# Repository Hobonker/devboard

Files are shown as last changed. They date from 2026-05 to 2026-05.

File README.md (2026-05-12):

# Devboard

# Inspiration 
I've never done such a large and complex custom PCB before, so I wanted to learn how to. The project helped me learn a lot about wiring and challenged me.
# What is it?
It's a custom PCB using an rp2040. Some other features are flash memory, USB-C power input, 12MHz crystal oscillator and a MCP1700 LDO voltage regulator.

# PCB
Here are some images of the board
Screenshot 2026-05-03 at 10.16.09 PM
Screenshot 2026-05-07 at 10 12 39 PM
Screenshot 2026-05-07 at 10 13 23 PM

# Bom
| Top Designator | Total Price ($) | Product Link |
|---|---|---|
| C1, C10 | 0.029 | https://jlcpcb.com/partdetail/53938-CL05A105KA5NQNC/C52923 |
| C8, C6, C5, C4, C2, C7, C11, C9, C12, C17, C3 | 0.0605 | https://jlcpcb.com/partdetail/1877-CL05B104KO5NNNC/C1525 |
| C13, C14 | 0.056 | https://jlcpcb.com/partdetail/20411-CL10A106KP8NNNC/C19702 |
| C16, C15 | 0.01 | https://jlcpcb.com/partdetail/1914-0402CG330J500NT/C1562 |
| J1 | 0.18 | https://jlcpcb.com/partdetail/Korean_HropartsElec-TYPE_C_31_M12/C165948 |
| J3, J2 | 0.14 | https://jlcpcb.com/partdetail/51993-2_54_1_20P/C50981 |
| J4 | 0.03 | https://jlcpcb.com/partdetail/25717-1_27_1_3P/C24980 |
| R2, R1 | 0.005 | https://jlcpcb.com/partdetail/26648-0402WGF5101TCE/C25905 |
| R3, R4 | 0.011 | https://jlcpcb.com/partdetail/25843-0402WGF270JTCE/C25100 |
| R6, R5 | 0.005 | https://jlcpcb.com/partdetail/12256-0402WGF1001TCE/C11702 |
| R7 | 0.0025 | https://jlcpcb.com/partdetail/26487-0402WGF1002TCE/C25744 |
| SW1 | 0.06 | https://jlcpcb.com/partdetail/XUNPU-TS_1088AR02016/C720477 |
| U1 | 0.98 | https://jlcpcb.com/partdetail/RaspberryPi-RP2040/C2040 |
| U2 | 0.49 | https://jlcpcb.com/partdetail/MicrochipTech-MCP1700T_3302ETT/C39051 |
| U4 | 0.71 | https://jlcpcb.com/partdetail/WinbondElec-W25Q16JVUXIQ/C2843335 |

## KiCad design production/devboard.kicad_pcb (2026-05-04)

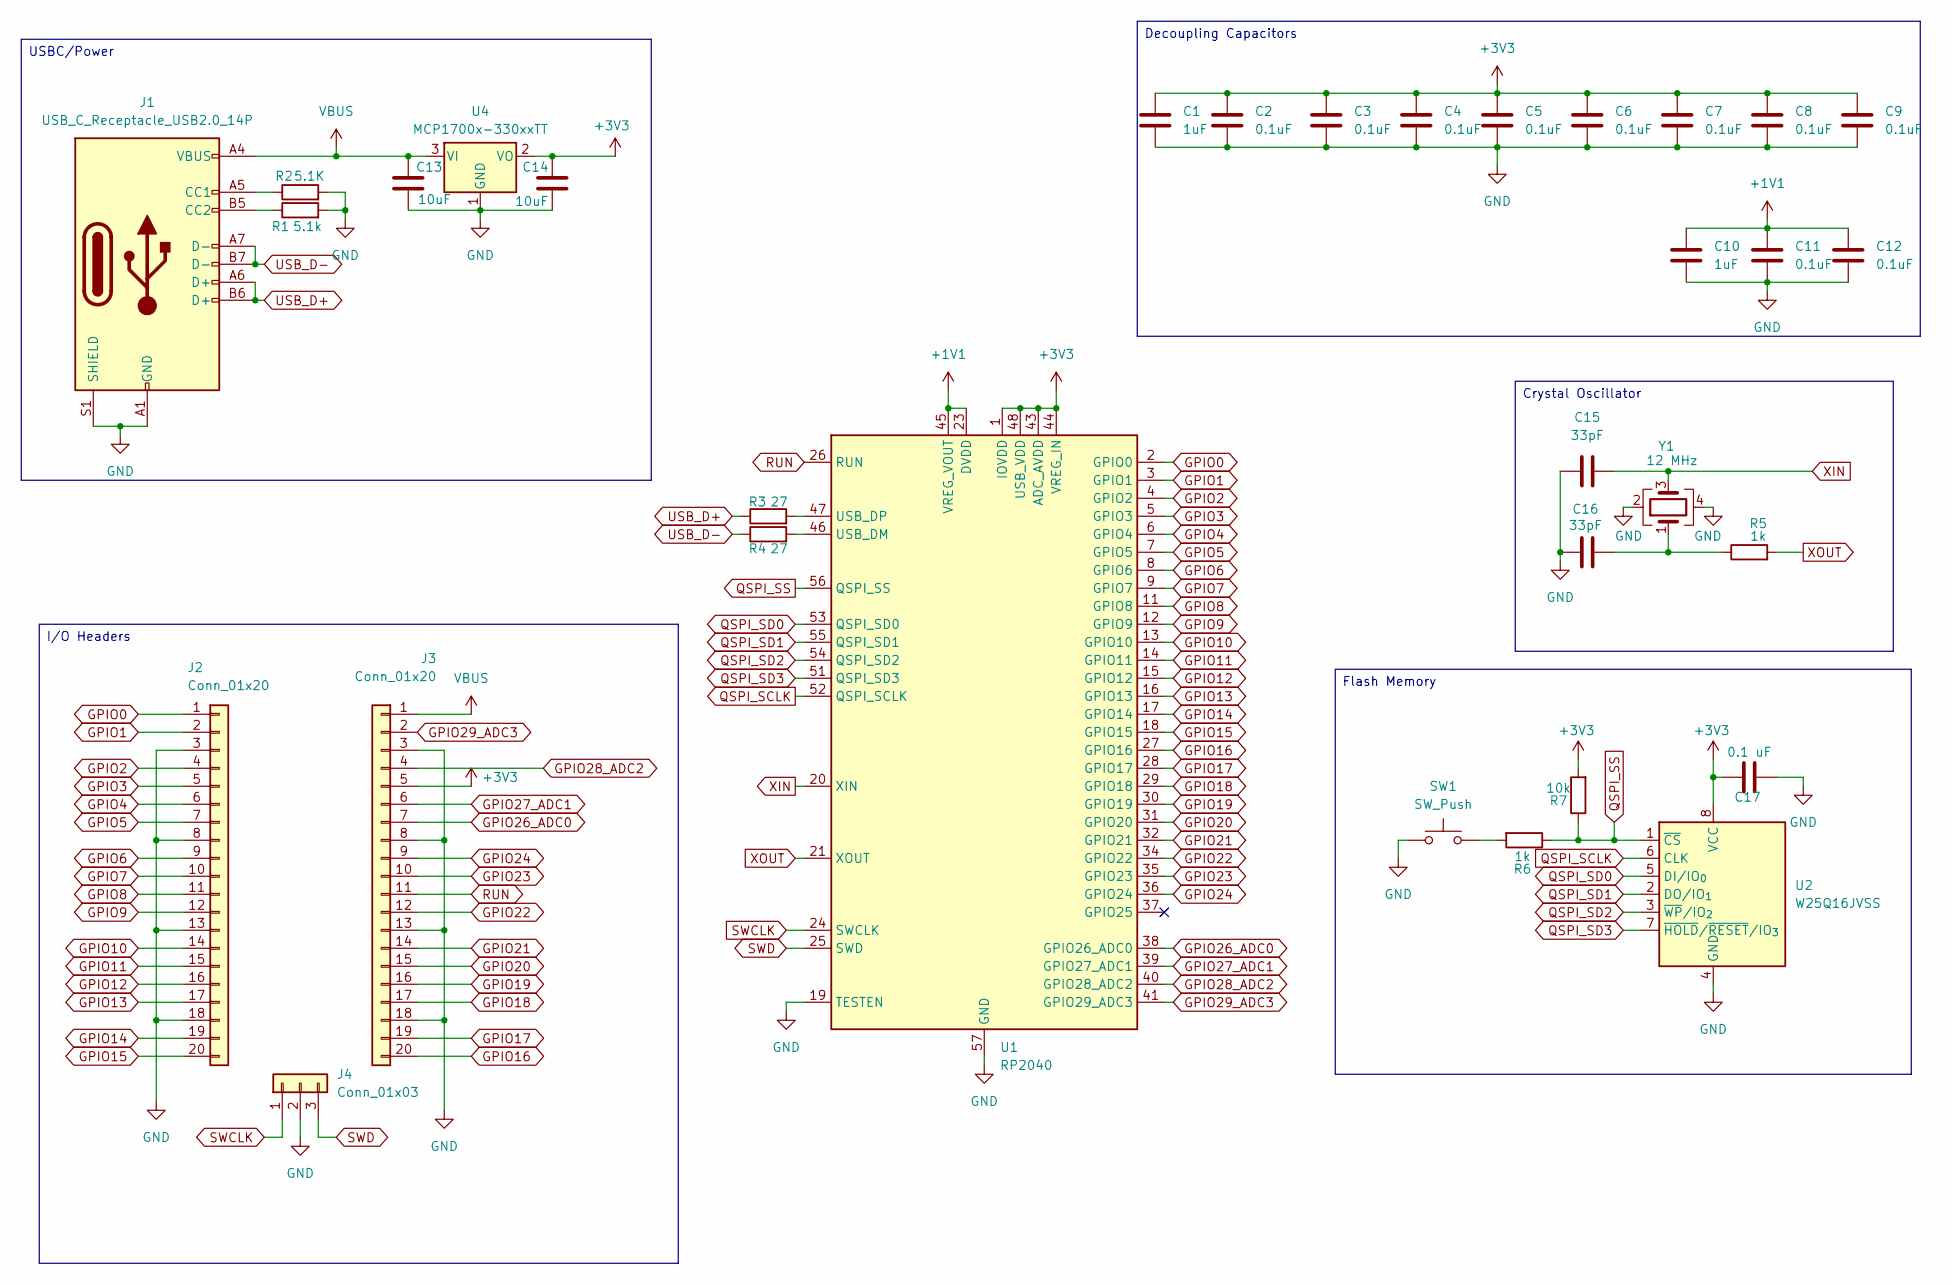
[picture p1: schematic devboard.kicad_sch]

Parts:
C1, C10: 1uF; C_0402_1005Metric
C2, C3, C4, C5, C6, C7, C8, C9, C11, C12: 0.1uF; C_0402_1005Metric
C13, C14: 10uF; C_0603_1608Metric
C15, C16: 33pF; C_0402_1005Metric
C17: 0.1 uF; C_0402_1005Metric
J1: USB_C_Receptacle_USB2.0_14P; USB_C_Receptacle_HRO_TYPE-C-31-M-12
J2, J3: Conn_01x20; PinHeader_1x20_P2.54mm_Vertical
J4: Conn_01x03; PinHeader_1x03_P2.54mm_Vertical
R1: 5.1k; R_0402_1005Metric
R2: 5.1K; R_0402_1005Metric
R3, R4: 27; R_0402_1005Metric
R5, R6: 1k; R_0402_1005Metric
R7: 10k; R_0402_1005Metric
SW1: SW_Push; SW_Push_SPST_NO_Alps_SKRK
U1: RP2040; QFN-56-1EP_7x7mm_P0.4mm_EP3.2x3.2mm
U2: W25Q16JVSS; Winbond_USON-8-1EP_3x2mm_P0.5mm_EP0.2x1.6mm
U4: MCP1700x-330xxTT; SOT-23
Y1: 12 MHz; Crystal_SMD_3225-4Pin_3.2x2.5mm

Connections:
+1V1: C10.1, C11.1, C12.1, U1.23 (DVDD), U1.45 (VREG_VOUT), U1.50 (DVDD)
+3V3: C1.1, C2.1, C3.1, C4.1, C5.1, C6.1, C7.1, C8.1, C9.1, C14.1, C17.1, J3.5, R7.2, U1.1 (IOVDD), U1.10 (IOVDD), U1.22 (IOVDD), U1.33 (IOVDD), U1.42 (IOVDD), U1.43 (ADC_AVDD), U1.44 (VREG_IN), U1.48 (USB_VDD), U1.49 (IOVDD), U2.8 (VCC), U4.2 (VO)
GND: C1.2, C2.2, C3.2, C4.2, C5.2, C6.2, C7.2, C8.2, C9.2, C10.2, C11.2, C12.2, C13.2, C14.2, C15.1, C16.1, C17.2, J1.A1 (GND), J1.A12 (GND), J1.B1 (GND), J1.B12 (GND), J1.S1 (SHIELD), J2.3, J2.8, J2.13, J2.18, J3.3, J3.8, J3.13, J3.18, J4.2, R1.2, R2.2, SW1.1, U1.19 (TESTEN), U1.57 (GND), U2.4 (GND), U4.1 (GND), Y1.2, Y1.4
GPIO0: J2.1, U1.2 (GPIO0)
GPIO1: J2.2, U1.3 (GPIO1)
GPIO2: J2.4, U1.4 (GPIO2)
GPIO3: J2.5, U1.5 (GPIO3)
GPIO4: J2.6, U1.6 (GPIO4)
GPIO5: J2.7, U1.7 (GPIO5)
GPIO6: J2.9, U1.8 (GPIO6)
GPIO7: J2.10, U1.9 (GPIO7)
GPIO8: J2.11, U1.11 (GPIO8)
GPIO9: J2.12, U1.12 (GPIO9)
GPIO10: J2.14, U1.13 (GPIO10)
GPIO11: J2.15, U1.14 (GPIO11)
GPIO12: J2.16, U1.15 (GPIO12)
GPIO13: J2.17, U1.16 (GPIO13)
GPIO14: J2.19, U1.17 (GPIO14)
GPIO15: J2.20, U1.18 (GPIO15)
GPIO16: J3.20, U1.27 (GPIO16)
GPIO17: J3.19, U1.28 (GPIO17)
GPIO18: J3.17, U1.29 (GPIO18)
GPIO19: J3.16, U1.30 (GPIO19)
GPIO20: J3.15, U1.31 (GPIO20)
GPIO21: J3.14, U1.32 (GPIO21)
GPIO22: J3.12, U1.34 (GPIO22)
GPIO23: J3.10, U1.35 (GPIO23)
GPIO24: J3.9, U1.36 (GPIO24)
GPIO26_ADC0: J3.7, U1.38 (GPIO26_ADC0)
GPIO27_ADC1: J3.6, U1.39 (GPIO27_ADC1)
GPIO28_ADC2: J3.4, U1.40 (GPIO28_ADC2)
GPIO29_ADC3: J3.2, U1.41 (GPIO29_ADC3)
unnamed: C16.2, R5.1, Y1.1
unnamed: J1.A5 (CC1), R2.1
unnamed: J1.B5 (CC2), R1.1
unnamed: R6.2, SW1.2
unnamed: R4.2, U1.46 (USB_DM)
unnamed: R3.2, U1.47 (USB_DP)
QSPI_SCLK: U1.52 (QSPI_SCLK), U2.6 (CLK)
QSPI_SD0: U1.53 (QSPI_SD0), U2.5 (DI/IO_{0})
QSPI_SD1: U1.55 (QSPI_SD1), U2.2 (DO/IO_{1})
QSPI_SD2: U1.54 (QSPI_SD2), U2.3 (~WP/IO_{2})
QSPI_SD3: U1.51 (QSPI_SD3), U2.7 (~HOLD/~RESET/IO_{3})
QSPI_SS: R6.1, R7.1, U1.56 (QSPI_SS), U2.1 (~CS)
RUN: J3.11, U1.26 (RUN)
SWCLK: J4.1, U1.24 (SWCLK)
SWD: J4.3, U1.25 (SWD)
USB_D+: J1.A6 (D+), J1.B6 (D+), R3.1
USB_D-: J1.A7 (D-), J1.B7 (D-), R4.1
VBUS: C13.1, J1.A4 (VBUS), J1.A9 (VBUS), J1.B4 (VBUS), J1.B9 (VBUS), J3.1, U4.3 (VI)
XIN: C15.2, U1.20 (XIN), Y1.3
XOUT: R5.2, U1.21 (XOUT)

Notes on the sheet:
Decoupling Capacitors
I/O Headers
Crystal Oscillator
USBC/Power
Flash Memory

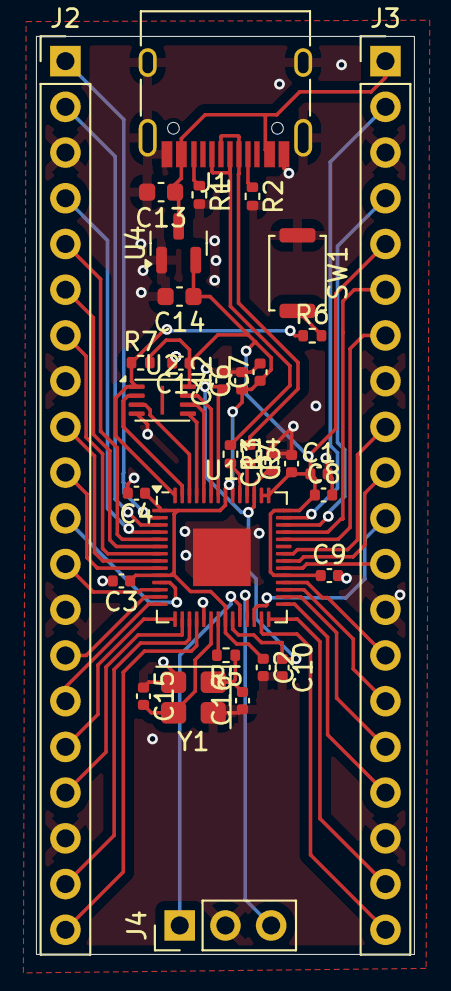
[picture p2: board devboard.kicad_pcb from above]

Board: 2 copper layers, 21.0 x 51.0 mm, 33 parts (0 on the bottom side), 52 nets.

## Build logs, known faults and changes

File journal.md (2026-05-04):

<!--
  This journal is auto generated by Stasis.
-->

# 5/4/2026 2 AM - Wiring Finished

_Time spent: 3.6h_

Screenshot 2026-05-03 at 10.16.09 PM

Finished wiring, first inital finish had 33 errors, manually troubleshooted every one. I had a lot of issues with the filling zones because this was my first time using them, but after moving a lot of the wires to remove isolated zones it resolved most of my errors.



# 5/3/2026 12 AM - Wiring

_Time spent: 2.183333333333333h_

j522

j521

(this was span over multiple sessions, I just forgot to journal one or two days)
I was wiring different parts together, finished assembly, had issues where wiring wasn't matching, I had accidently switched two of the resistors around in the original schematic, which I fixed. Doing the pairs for wiring and etc.

I mostly avoided the vias, I'll set them up next, I also need to go back and change some of the wiring because they're currently at 90 degree angles.




# 4/3/2026 2 PM - Continuing PCB editing + Fixing previous component

_Time spent: 1.933333333333333h_

J4I1

J4I2

I continued assembling the PCB. I put roughly half of my Rs and Cs before I decided to stop due to the guide images being super difficult to read. I ended up downloading the source files from Github to look at through another instance of KiCad. I had a lot of the orientation of the Rs and Cs wrong so I ended up redoing/reorienting most of the ones I had already placed.

I took the opportunity to take a look at the W25Q16JVZPIQ TR in the schematic on Github. I ended up pasting it into my schematic and trying to use the symbol editor to save this as a new symbol under the memory flash library.

I kept getting the pop up that said this symbol already exists in memory flash, but when I left and checked for it using a, the symbol still wouldn't appear. I kept trying to figure out what happened and eventually noticed that whenever I tried to edit W25Q16JVZPIQ TR in the symbol library, KiCad would automatiically change the name to W25Q16JVSS even though the symbol was already named W25Q16JVZPIQ TR. This is also what was causing the pop up in memory flash to say symbol already exists, since I already have a W25Q16JVSS. The library ended up just having a shorthand for the name and I replaced the part and switched out the fooprint.




# 4/3/2026 3 AM - PCB Editing

_Time spent: 4.066666666666666h_

J3I2

J3I3

First worked on assigning all the footprints and it was very very very tedious.

I started working in the PCB editor but whenever I tried to use a local center for the relative positioning, it would send my component all the way to corner of the editor. I tried changing using different settings but eventually just had to position everything relative to the Edge.Cut rectangle.

I replaced the NCP1700 with the MCP1700x-330xxTT and was trying to find which footprint I should change it to but from what I could find online they share the same footprint of SOT-23.

I couldn't find W25Q16JVZPIQ TR anywhere in my symbol libraries despite searching all over the place. I looked online for other replacements but after looking forward in the guide, the final devboard ends up with some blank space so I ended up sticking with the previous component and keeping the same footprint despite the large size of the component.

Whenever I kept trying to flip the USBC port around it kept flipping horizontally. I did some digging online and I realized the flipping was not vert/horz but it was rather the face of the USBC, so I ended up using a rotation instead. I hope that was the right way to do it because some sources online said that I could edit the footprint manually and flip the USBC to be default facing that way. I'll find out whether it's right or not when I start wiring.

I spent a lot of time just trying to troubleshoot said issues and looking online. I still don't know what's wrong with my library and why it doesn't have the W25Q16JVZPIQ TR.




# 4/2/2026 8 PM - Finishing Schematic

_Time spent: 2.283333333333333h_

J2I1

J2I2

J2I3

Learning how flash storage works, then wired the flash storage.

Added labels to the main board on all the pins. I accidentally made them all inputs, but I found I could change them all at the same time through the properties tab on the left of KiCad. Also filled in the resistance values for USB D + & - as I forgot to do that before.

Finished wiring the I/O headers, I accidentally started with the pins Conn_01x20, and realized that it didn't look right. Found the correct Conn_01x03 and realized what I was doing wrong for the others.

Text boxes for each section, reorganizing and grouping.





# 4/2/2026 4 PM - KiCad

_Time spent: 2.583333333333333h_

Screenshot 2026-04-02 at 12.35.24 PM

Screenshot 2026-04-02 at 11.20.21 AM

I spent a few minutes jogging my memory on all the kicad keybinds and then I started working on the guide. 

Mostly just wiring, I spent some time going through the RP2040 datasheet. I only went through a few pages that were relevant. Reading 642 pages is probably overkill and unnessecary.

I ended up messing up the crystal oscillator so I redid that, hence why it's lacking in one of the images.

I started getting into Flash Storage but after getting into it a bit, it seemed like a good idea to take a break.
